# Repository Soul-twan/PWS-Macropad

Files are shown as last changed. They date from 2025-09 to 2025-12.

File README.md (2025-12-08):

Code and files I wrote for a school research project.

This project uses a Raspberry Pi Pico 2 family microcontroller to make a reprogrammable macropad. The microncontroller code is based on code from the Adafruit TinyUSB Library for Arduino (https://github.com/adafruit/Adafruit_TinyUSB_Arduino/blob/master/examples/HID/hid_composite/hid_composite.ino).

Microcontroller setup guide:
-

  1. Connect the microcontroller to your computer as a mass storage device by holding the button labelled "Bootsel" while plugging the USB-connector into your computer, it should show up as "RP2350"
  2. Download the latest release of the microcontroller code 
  3. Extract the downloaded "Microcontroller.code.zip" file 
  4. Move the folder labelled "Microcontroller code" over to the root of the Pico. Be sure to move the entire folder, not just its contents

If done properly, the Pico should disconnect automatically after moving over the folder.

PCB:
-
PCB designed with KiCad 9.0 and should work with PCB ordering services such as PCBWay.

Code compilation guide:
-

  1. Download the Arduino IDE
  2. Open MicrocontrollerCode.ino in the IDE
  3. In the menubar go to File > Preferences > Settings and add "https://github.com/earlephilhower/arduino-pico/releases/download/global/package_rp2040_index.json" to the Additional boards manager URLs
  4. In the boards manager in the sidebar install "Raspberry Pi Pico/RP2040/RP2350" by Earle F. Philhower, |||
  5. In the library manager in the sidebar install "Adafruit TinyUSB Library" by Adafruit
  6. In the dropdown below the menubar press "Select other boards and port...", then select the USB port that the raspberry pi is connected to and search and select the correct Raspberry Pi Pico model
  7. In the menubar go to Tools > USB Stack and select Adafruit TinyUSB\
  8. Press upload

If done properly, the code should be compiled and automatically uploaded to the microcontroller

Standard keymaps:
-

Encoders:
 1. Press: switch keymap, Turn: change screen brightness
 2. Press: mute volume, Turn: change volume

Keymap 1:  Sends signals to the companion app

  1. F13
  2. F14
  3. F15
  4. F16
  5. F17
  6. F18
  7. F19
  8. F20
  9. F21
  10. F22
  11. F23
  12. F24

Keymap 2: Mouse

 1. Left click
 2. Middle click
 3. Right click
 4. Scroll up
 5. Move mouse up
 6. Scroll down
 7. Move mouse left
 8. Scroll lock
 9. Move mouse right
 10. Scroll left
 11. Move mouse down
 12. Scroll right

Keymap 3: Various shortcuts

 1. Previous track
 2. Next track
 3. Play/pause
 4. Ctrl + x
 5. Ctrl + c
 6. Ctrl + v
 7. Ctrl + z
 8. Ctrl + s
 9. Alt + tab
 10. Calculator
 11. Screenshot
 12. Delete

Components:
- 
Off the shelf:
 - PEC12R-4217F-S0024 rotary encoder
 - Kaihl hotswap sockets for cherry mx
 - Cherry MX keyswitches
 - Raspberry Pi Pico 2 + socket
 - Keycaps for cherry mx (optional)

Custom:
 - PCB
 - 3d printed case
 - 3d printed knobs
 - 3d printed keycaps

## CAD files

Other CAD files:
PWScase.blend

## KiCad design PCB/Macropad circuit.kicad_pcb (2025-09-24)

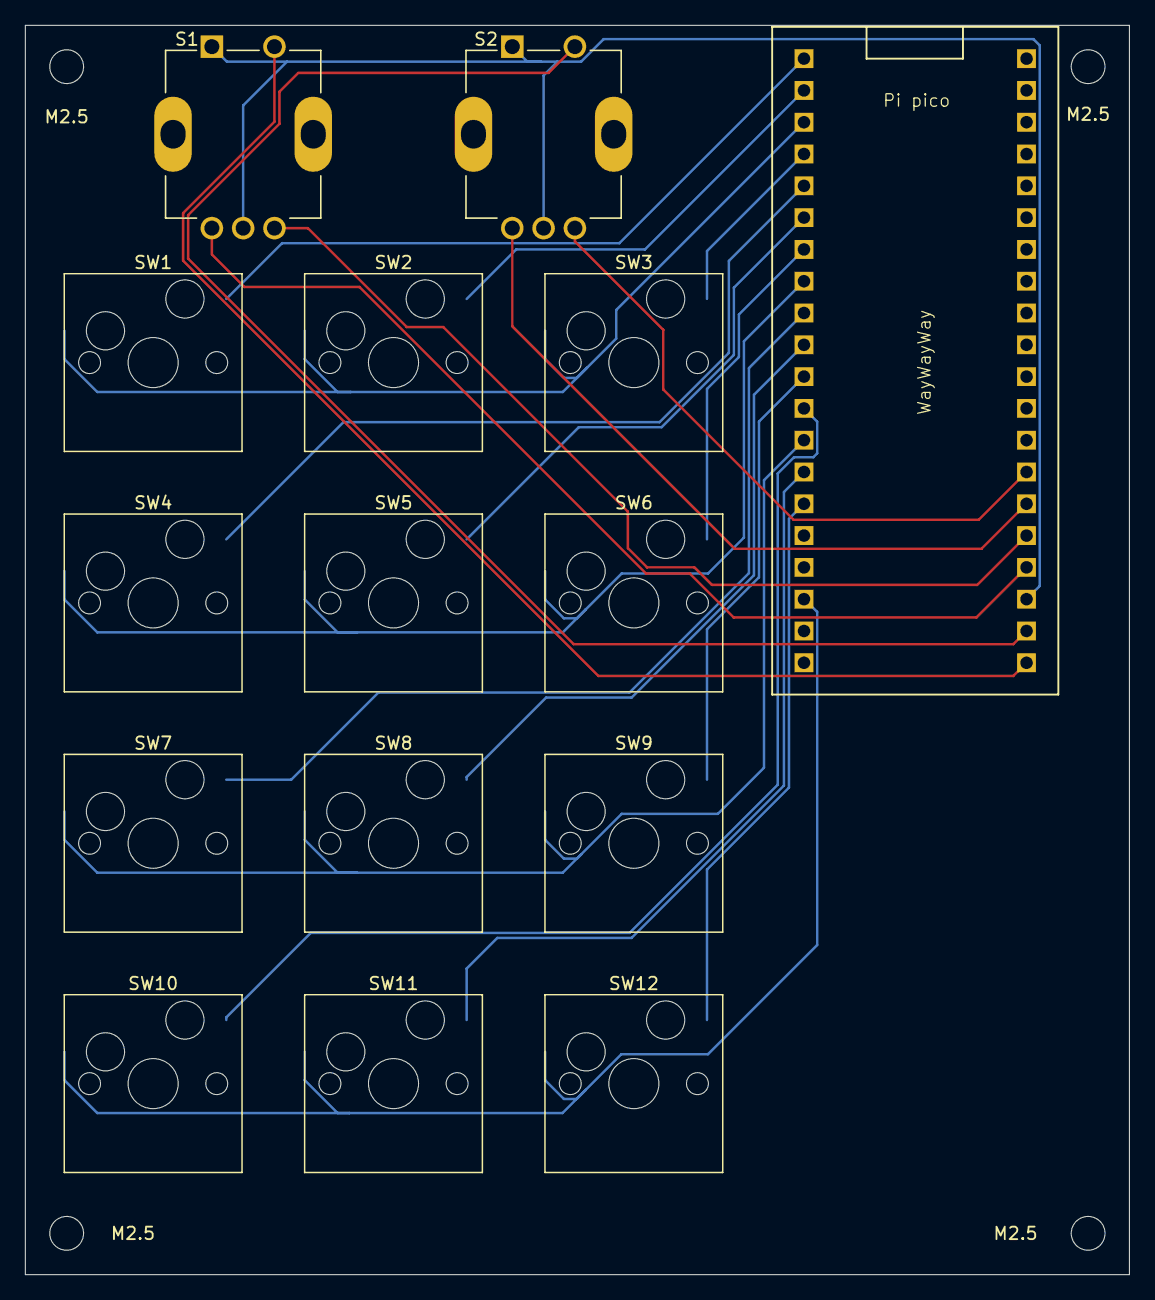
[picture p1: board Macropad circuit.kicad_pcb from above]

Board: 2 copper layers, 88.2 x 99.8 mm, 19 parts (0 on the bottom side), 23 nets.

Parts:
M2.5, M2.5#2, M2.5#3, M2.5#4: MountingHole_2.7mm_M2.5
Pi pico: Raspberrypi pico2 THT
S1, S2: PEC12R-4230F-S0024; XDCR_PEC12R-4230F-S0024
SW1, SW2, SW3, SW4, SW5, SW6, SW7, SW8, SW9, SW10, SW11, SW12: CherryMX; SW_Hotswap_Kailh_MX_1.00u

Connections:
Button1: Pi pico.GP0, SW1.2
Button2: Pi pico.GP1, SW2.2
Button3: Pi pico.GP2, SW3.2
Button4: Pi pico.GP3, SW4.2
Button5: Pi pico.GP4, SW5.2
Button6: Pi pico.GP5, SW6.2
Button7: Pi pico.GP6, SW7.2
Button8: Pi pico.GP7, SW8.2
Button9: Pi pico.GP8, SW9.2
Button10: Pi pico.GP9, SW10.2
Button11: Pi pico.GP10, SW11.2
Button12: Pi pico.GP11, SW12.2
EncoderButton1: Pi pico.GP16, S1.2
EncoderButton2: Pi pico.GP17, S2.2
EncoderChannel1: Pi pico.GP18, S1.A (CHANNEL_A)
EncoderChannel2: Pi pico.GP19, S1.B (CHANNEL_B)
EncoderChannel3: Pi pico.GP20, S2.A (CHANNEL_A)
EncoderChannel4: Pi pico.GP21, S2.B (CHANNEL_B)
EncoderGround: Pi pico.GND, S1.1, S1.C (COMMON), S2.1, S2.C (COMMON)
GroundButtonRow1: Pi pico.GND, SW1.1, SW2.1, SW3.1
GroundButtonRow2: Pi pico.GND, SW4.1, SW5.1, SW6.1
GroundButtonRow3: Pi pico.GND, SW7.1, SW8.1, SW9.1
GroundButtonRow4: Pi pico.GND, SW10.1, SW11.1, SW12.1

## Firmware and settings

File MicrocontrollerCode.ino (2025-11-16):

 /*********************************************************************
 Based on example code by Adafruit
 
 MIT license, check LICENSE for more information
 Copyright (c) 2025 Twan Kneppers
 All text above must be included in any redistribution
*********************************************************************/

#include "Adafruit_TinyUSB.h"

// Digital pin designation
// Numbers in this array are GPIO pins
const int buttonPins[12] = {0, 1, 2, 3, 4, 5, 6, 7, 8, 9, 10, 11};

const int encoderOneChannelA = 18;
const int encoderOneChannelB = 19;
const int encoderOneBtn = 16;

const int encoderTwoChannelA = 20;
const int encoderTwoChannelB = 21;
const int encoderTwoBtn = 17;

const int keymapSwitcherPin = encoderOneBtn;

bool keymapSwitcherUsed = false;
int keymapIndex = 0;

/*
Layout:
_________________________________________________
|              ____             ____            |
|             / e1 \           / e2 \           |
|             \____/           \____/           |
|                                               |
|  __________       __________      __________  |
|  |        |       |        |      |        |  |
|  |    1   |       |    2   |      |    3   |  |
|  |________|       |________|      |________|  |
|  __________       __________      __________  |
|  |        |       |        |      |        |  |
|  |    4   |       |    5   |      |    6   |  |
|  |________|       |________|      |________|  |
|  __________       __________      __________  |
|  |        |       |        |      |        |  |
|  |    7   |       |    8   |      |    9   |  |
|  |________|       |________|      |________|  |
|  __________       __________      __________  |
|  |        |       |        |      |        |  |
|  |    10  |       |    11  |      |    12  |  |
|  |________|       |________|      |________|  |
|_______________________________________________|

The keymap array is structured as follows:

{ Keymap 1 {
  Key 1 {[0],[1],[2],[3],[4],[5],[6]},[7],[8],[9],[10],[11],[12],[13]},
  Key 2 {[0],[1],[2],[3],[4],[5],[6]},[7],[8],[9],[10],[11],[12],[13]},
  .
  .
  .
  Key 12 {[0],[1],[2],[3],[4],[5],[6]},[7],[8],[9],[10],[11],[12],[13]}},
Keymap 2 {
  Key 1 {[0],[1],[2],[3],[4],[5],[6]},[7],[8],[9],[10],[11],[12],[13]},
  Key 2 {[0],[1],[2],[3],[4],[5],[6]},[7],[8],[9],[10],[11],[12],[13]},
  .
  .
  .
  Key 12 {[0],[1],[2],[3],[4],[5],[6]},[7],[8],[9],[10],[11],[12],[13]}},
Keymap 3 {
  Key 1 {[0],[1],[2],[3],[4],[5],[6]},[7],[8],[9],[10],[11],[12],[13]},
  Key 2 {[0],[1],[2],[3],[4],[5],[6]},[7],[8],[9],[10],[11],[12],[13]},
  .
  .
  .
  Key 12 {[0],[1],[2],[3],[4],[5],[6]},[7],[8],[9],[10],[11],[12],[13]}}
}


For a list of all possible controls go to https://github.com/hathach/tinyusb/blob/master/src/class/hid/hid.h
[0] mouse button
[1] mouse delta
[2] mouse X direction:   -1 for left and 1 for right
[3] mouse Y direction:   -1 for up and 1 for down
[4] scroll delta
[5] scroll y direction:  -1 for right and 1 for left
[6] scroll x direction:  -1 for left and 1 for right
[7-12] keyboard keys
[13] consumer control
Value should be 0 if not applicable
Mouse direction = 0 if no movement
Mouse button and mouse movement can't happen on the same key
*/
const int keymap[3][12][14] = {
  {{0, 0, 0, 0, 0, 0, 0, HID_KEY_F13, 0, 0, 0, 0, 0, 0},
  {0, 0, 0, 0, 0, 0, 0, HID_KEY_F14, 0, 0, 0, 0, 0, 0},
  {0, 0, 0, 0, 0, 0, 0, HID_KEY_F15, 0, 0, 0, 0, 0, 0},
  {0, 0, 0, 0, 0, 0, 0, HID_KEY_F16, 0, 0, 0, 0, 0, 0},
  {0, 0, 0, 0, 0, 0, 0, HID_KEY_F17, 0, 0, 0, 0, 0, 0},
  {0, 0, 0, 0, 0, 0, 0, HID_KEY_F18, 0, 0, 0, 0, 0, 0},
  {0, 0, 0, 0, 0, 0, 0, HID_KEY_F19, 0, 0, 0, 0, 0, 0},
  {0, 0, 0, 0, 0, 0, 0, HID_KEY_F20, 0, 0, 0, 0, 0, 0},
  {0, 0, 0, 0, 0, 0, 0, HID_KEY_F21, 0, 0, 0, 0, 0, 0},
  {0, 0, 0, 0, 0, 0, 0, HID_KEY_F22, 0, 0, 0, 0, 0, 0},
  {0, 0, 0, 0, 0, 0, 0, HID_KEY_F23, 0, 0, 0, 0, 0, 0},
  {0, 0, 0, 0, 0, 0, 0, HID_KEY_F24, 0, 0, 0, 0, 0, 0}},

  {{MOUSE_BUTTON_LEFT, 0, 0, 0, 0, 0, 0, 0, 0, 0, 0, 0, 0, 0},
  {MOUSE_BUTTON_MIDDLE, 0, 0, 0, 0, 0, 0, 0, 0, 0, 0, 0, 0, 0},
  {MOUSE_BUTTON_RIGHT, 0, 0, 0, 0, 0, 0, 0, 0, 0, 0, 0, 0, 0},
  {0, 0, 0, 0, 1, 1, 0, 0, 0, 0, 0, 0, 0, 0},
  {0, 10, 0, -1, 0, 0, 0, 0, 0, 0, 0, 0, 0, 0},
  {0, 0, 0, 0, 1, -1, 0, 0, 0, 0, 0, 0, 0, 0},
  {0, 10, -1, 0, 0, 0, 0, 0, 0, 0, 0, 0, 0, 0},
  {0, 0, 0, 0, 0, 0, 0, HID_KEY_SCROLL_LOCK, 0, 0, 0, 0, 0, 0},
  {0, 10, 1, 0, 0, 0, 0, 0, 0, 0, 0, 0, 0, 0},
  {0, 0, 0, 0, 1, 0, -1, 0, 0, 0, 0, 0, 0, 0},
  {0, 10, 0, 1, 0, 0, 0, 0, 0, 0, 0, 0, 0, 0},
  {0, 0, 0, 0, 1, 0, 1, 0, 0, 0, 0, 0, 0, 0}},

  {{0, 0, 0, 0, 0, 0, 0, 0, 0, 0, 0, 0, 0, HID_USAGE_CONSUMER_SCAN_PREVIOUS_TRACK},
  {0, 0, 0, 0, 0, 0, 0, 0, 0, 0, 0, 0, 0, HID_USAGE_CONSUMER_SCAN_NEXT_TRACK},
  {0, 0, 0, 0, 0, 0, 0, 0, 0, 0, 0, 0, 0, HID_USAGE_CONSUMER_PLAY_PAUSE},
  {0, 0, 0, 0, 0, 0, 0, HID_KEY_CONTROL_LEFT, HID_KEY_X, 0, 0, 0, 0, 0},
  {0, 0, 0, 0, 0, 0, 0, HID_KEY_CONTROL_LEFT, HID_KEY_C, 0, 0, 0, 0, 0},
  {0, 0, 0, 0, 0, 0, 0, HID_KEY_CONTROL_LEFT, HID_KEY_V, 0, 0, 0, 0, 0},
  {0, 0, 0, 0, 0, 0, 0, HID_KEY_CONTROL_LEFT, HID_KEY_Z, 0, 0, 0, 0, 0},
  {0, 0, 0, 0, 0, 0, 0, HID_KEY_CONTROL_LEFT, HID_KEY_S, 0, 0, 0, 0, 0},
  {0, 0, 0, 0, 0, 0, 0, HID_KEY_ALT_LEFT, HID_KEY_TAB, 0, 0, 0, 0, 0},
  {0, 0, 0, 0, 0, 0, 0, 0, 0, 0, 0, 0, 0, HID_USAGE_CONSUMER_AL_CALCULATOR},
  {0, 0, 0, 0, 0, 0, 0, HID_KEY_PRINT_SCREEN, 0, 0, 0, 0, 0, 0},
  {0, 0, 0, 0, 0, 0, 0, HID_KEY_DELETE, 0, 0, 0, 0, 0, 0}}
  };

int mouseButtonPin = -1;
int pressedKeyPin = -1;
int consumerControlPinIndex = -1;

bool hasMouseButton = false;
bool hasKeyboardKey = false;
bool consumerKeyUsed = false;

bool encoderTwoBtnUsed = false;

// 0 clockwise, 1 counter clockwise
int encoderOneDirection = -1;
int encoderTwoDirection = -1;

bool encoderOneSent = false;
bool encoderTwoSent = false;

// Report ID
enum {
  RID_KEYBOARD = 1,
  RID_MOUSE,
  RID_CONSUMER_CONTROL,
};

// HID report descriptor using TinyUSB's template
uint8_t const desc_hid_report[] = {
    TUD_HID_REPORT_DESC_KEYBOARD(HID_REPORT_ID(RID_KEYBOARD)),
    TUD_HID_REPORT_DESC_MOUSE   (HID_REPORT_ID(RID_MOUSE)),
    TUD_HID_REPORT_DESC_CONSUMER(HID_REPORT_ID(RID_CONSUMER_CONTROL))
};

// USB HID object.
Adafruit_USBD_HID usb_hid;

// the setup function runs once when you press reset or power the board
void setup() {
  // Manual begin() is required on core without built-in support e.g. mbed rp2040
  if (!TinyUSBDevice.isInitialized()) {
    TinyUSBDevice.begin(0);
  }

  Serial.begin(115200);

  // Set up HID
  usb_hid.setPollInterval(2);
  usb_hid.setReportDescriptor(desc_hid_report, sizeof(desc_hid_report));
  usb_hid.setStringDescriptor("Macropad");
  usb_hid.begin();

  // If already enumerated, additional class driverr begin() e.g msc, hid, midi won't take effect until re-enumeration
  if (TinyUSBDevice.mounted()) {
    TinyUSBDevice.detach();
    delay(10);
    TinyUSBDevice.attach();
  }

  // Sets up button pins
  for (int pinIndex = 0; pinIndex < 12; pinIndex++) {
    pinMode(buttonPins[pinIndex], INPUT_PULLUP);
  }

  pinMode(encoderOneChannelA, INPUT_PULLUP);
  pinMode(encoderOneChannelB, INPUT_PULLUP);
  pinMode(encoderOneBtn, INPUT_PULLUP);
  pinMode(encoderTwoChannelA, INPUT_PULLUP);
  pinMode(encoderTwoChannelB, INPUT_PULLUP);
  pinMode(encoderTwoBtn, INPUT_PULLUP);
  pinMode(keymapSwitcherPin, INPUT_PULLUP);
}

void keymapSwitcher() {
  if (digitalRead(keymapSwitcherPin) == LOW && !keymapSwitcherUsed) {
    keymapSwitcherUsed = true;
    if (keymapIndex == 2) { 
      keymapIndex = 0;
    }
    else {
      keymapIndex++;
    }
  }
  else if (digitalRead(keymapSwitcherPin) == HIGH && keymapSwitcherUsed) {
    keymapSwitcherUsed = false;
    delay(10);
  }
}

void keys() {
  // Remote wakeup
  int digitalPinSum = 0;
  bool anyKeyPressed = false;

  for (int pinIndex = 0; pinIndex < 12; pinIndex++) {
    digitalPinSum = digitalPinSum + digitalRead(buttonPins[pinIndex]);
  }

  if (digitalPinSum < 12) {
    anyKeyPressed = true;
  }

  if (TinyUSBDevice.suspended() && anyKeyPressed == true) {
    TinyUSBDevice.remoteWakeup();
  }

  if (usb_hid.ready()) {

    // Mouse button release
    if (mouseButtonPin != -1 && hasMouseButton) {
      if (digitalRead(mouseButtonPin) == HIGH) {
        usb_hid.mouseButtonRelease(RID_MOUSE);
        hasMouseButton = false;
        mouseButtonPin = -1;
        delay(10);
      }
    }

    // Keyboard key release
    if (pressedKeyPin != -1 && hasKeyboardKey) {
      if (digitalRead(pressedKeyPin) == HIGH) {
        usb_hid.keyboardRelease(RID_KEYBOARD);
        pressedKeyPin = -1;
        hasKeyboardKey = false;
        delay(10);
      }
    }

    // Consumer key release
    if (consumerControlPinIndex != -1 && consumerKeyUsed) {
      if (digitalRead(buttonPins[consumerControlPinIndex]) == HIGH) {
        usb_hid.sendReport16(RID_CONSUMER_CONTROL, HID_KEY_NONE);
        consumerKeyUsed = false;
        consumerControlPinIndex = -1;
        delay(10);
      }
    }

    if (anyKeyPressed == true) {
      for (int pinIndex = 0; pinIndex < 12; pinIndex++) {

        // Mouse control
        if (digitalRead(buttonPins[pinIndex]) == LOW) {    
          int mouseDelta = keymap[keymapIndex][pinIndex][1];

          if (mouseDelta > 0) {
            int deltaX = keymap[keymapIndex][pinIndex][2] * mouseDelta;
            int deltaY = keymap[keymapIndex][pinIndex][3] * mouseDelta;
            //Calculated from top left of display
            usb_hid.mouseMove(RID_MOUSE, deltaX, deltaY);
            delay(10);
          }
          else if (keymap[keymapIndex][pinIndex][0] != 0 && !hasMouseButton) {
            usb_hid.mouseButtonPress(RID_MOUSE, keymap[keymapIndex][pinIndex][0]);
            hasMouseButton = true;
            mouseButtonPin = pinIndex;
            delay(10);
          }
          else if (keymap[keymapIndex][pinIndex][4] != 0) {
            int scrollDelta = keymap[keymapIndex][pinIndex][4];
            int verticalScrollDirection = keymap[keymapIndex][pinIndex][5];
            int horizontalScrollDirection = keymap[keymapIndex][pinIndex][6];

            int verticalScroll = scrollDelta * verticalScrollDirection;
            int horizontalScroll = scrollDelta * horizontalScrollDirection;

            usb_hid.mouseScroll(RID_MOUSE, verticalScroll, horizontalScroll);
            delay(10);
          }
        }

        // Keyboard control
        if (digitalRead(buttonPins[pinIndex]) == LOW && keymap[keymapIndex][pinIndex][7] != 0 && !hasKeyboardKey) {
          // A maximum of 6 keys can be sent in 1 report
          // Adding to the keycode array adds a key that is being 'pressed' in order from 0 to 5
          uint8_t keycode[6] = {0};
        
          for (int codeIndex = 0; codeIndex < 6; codeIndex++) {
            keycode[codeIndex] = keymap[keymapIndex][pinIndex][(codeIndex + 7)];
          }

          usb_hid.keyboardReport(RID_KEYBOARD, 0, keycode);
          pressedKeyPin = buttonPins[pinIndex];
          hasKeyboardKey = true;
          delay(10);
        } 

        // Consumer control
        if (digitalRead(buttonPins[pinIndex]) == LOW && !consumerKeyUsed) {
          usb_hid.sendReport16(RID_CONSUMER_CONTROL, keymap[keymapIndex][pinIndex][13]);
          consumerKeyUsed = true;
          consumerControlPinIndex = pinIndex;
          delay (10);
        } 
      }  
    }
  }
}

void encoderOne() {
  // Rotation
  if (encoderOneDirection == -1 && digitalRead(encoderOneChannelA) == LOW && digitalRead(encoderOneChannelB) == HIGH) {
    encoderOneDirection = 0;
  }
  else if (encoderOneDirection == -1 && digitalRead(encoderOneChannelA) == HIGH && digitalRead(encoderOneChannelB) == LOW) {
    encoderOneDirection = 1;
  }
  else if (encoderOneDirection != -1 && usb_hid.ready() && digitalRead(encoderOneChannelA) == HIGH && digitalRead(encoderOneChannelB) == HIGH) {
    if (!encoderOneSent) {
      if (encoderOneDirection == 0) {
        usb_hid.sendReport16(RID_CONSUMER_CONTROL, HID_USAGE_CONSUMER_BRIGHTNESS_INCREMENT);
        delay(10);
      }
      else {
        usb_hid.sendReport16(RID_CONSUMER_CONTROL, HID_USAGE_CONSUMER_BRIGHTNESS_DECREMENT);
        delay(10);
      }
      encoderOneSent = true;
    }
    else {
      usb_hid.sendReport16(RID_CONSUMER_CONTROL, HID_KEY_NONE);
      encoderOneDirection = -1;
      encoderOneSent = false;
      delay(10);
    }
  }
}

void encoderTwo() {
  // Rotation
  if (encoderTwoDirection == -1 && digitalRead(encoderTwoChannelA) == LOW && digitalRead(encoderTwoChannelB) == HIGH) {
    encoderTwoDirection = 0;
  }
  else if (encoderTwoDirection == -1 && digitalRead(encoderTwoChannelA) == HIGH && digitalRead(encoderTwoChannelB) == LOW) {
    encoderTwoDirection = 1;
  }
  else if (encoderTwoDirection != -1 && usb_hid.ready() && digitalRead(encoderTwoChannelA) == HIGH && digitalRead(encoderTwoChannelB) == HIGH) {
    if (!encoderTwoSent) {
      if (encoderTwoDirection == 0) {
        usb_hid.sendReport16(RID_CONSUMER_CONTROL, HID_USAGE_CONSUMER_VOLUME_INCREMENT);
        delay(10);
      }
      else {
        usb_hid.sendReport16(RID_CONSUMER_CONTROL, HID_USAGE_CONSUMER_VOLUME_DECREMENT);
        delay(10);
      }
      encoderTwoSent = true;
    }
    else {
      usb_hid.sendReport16(RID_CONSUMER_CONTROL, HID_KEY_NONE);
      encoderTwoDirection = -1;
      encoderTwoSent = false;
      delay(10);
    }
  }

  // Button
  if (usb_hid.ready()) {
    if (encoderTwoBtnUsed && digitalRead(encoderTwoBtn) == HIGH) {
      usb_hid.sendReport16(RID_CONSUMER_CONTROL, HID_KEY_NONE);
      encoderTwoBtnUsed = false;   
      delay(10);
    }
    else if (!encoderTwoBtnUsed && digitalRead(encoderTwoBtn) == LOW) {
      usb_hid.sendReport16(RID_CONSUMER_CONTROL, HID_USAGE_CONSUMER_MUTE);
      encoderTwoBtnUsed = true;
      delay (10);
    }
  }
}

void loop() {
  #ifdef TINYUSB_NEED_POLLING_TASK
  // Manual call tud_task since it isn't called by Core's background
  TinyUSBDevice.task();
  #endif

  // not enumerated()/mounted() yet: nothing to do
  if (!TinyUSBDevice.mounted()) {
    return;
  }

  // Switches keymap on button press
  keymapSwitcher();

  // Encoder one
  encoderOne();

  // Encoder two
  encoderTwo();

  keys();
}

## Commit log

2025-07-26 Update MicrocontrollerCode.ino
    Fixed license and massively improved functionality and modularity
    [MicrocontrollerCode.ino]
2025-07-29 Update MicrocontrollerCode.ino
    Fixed bugs and added keymap switching
    [MicrocontrollerCode.ino]
2025-08-22 Update MicrocontrollerCode.ino
    Added rotary encoders and optimized a bit
2025-08-23 Update MicrocontrollerCode.ino
    Improved encoder performance and organized functions
2025-08-23 Update MicrocontrollerCode.ino
    Switched out standard shortcuts and proved myself wrong (turned assigning keys in the array into a for loop)
    [MicrocontrollerCode.ino]
2025-09-09 Update MicrocontrollerCode.ino
    Changed standard shortcuts and updated for new tinyusb library version
    [MicrocontrollerCode.ino]
2025-09-24 Added PCB schematics
    [Macropad circuit.kicad_pcb, Macropad circuit.kicad_sch]
2025-10-16 Update MicrocontrollerCode.ino
    Changed standard shortcuts to be a better example and added some commentary
    [MicrocontrollerCode.ino]
2025-11-23 Added case model
    Case, knobs and keycaps model design file
    [PWScase.blend]
